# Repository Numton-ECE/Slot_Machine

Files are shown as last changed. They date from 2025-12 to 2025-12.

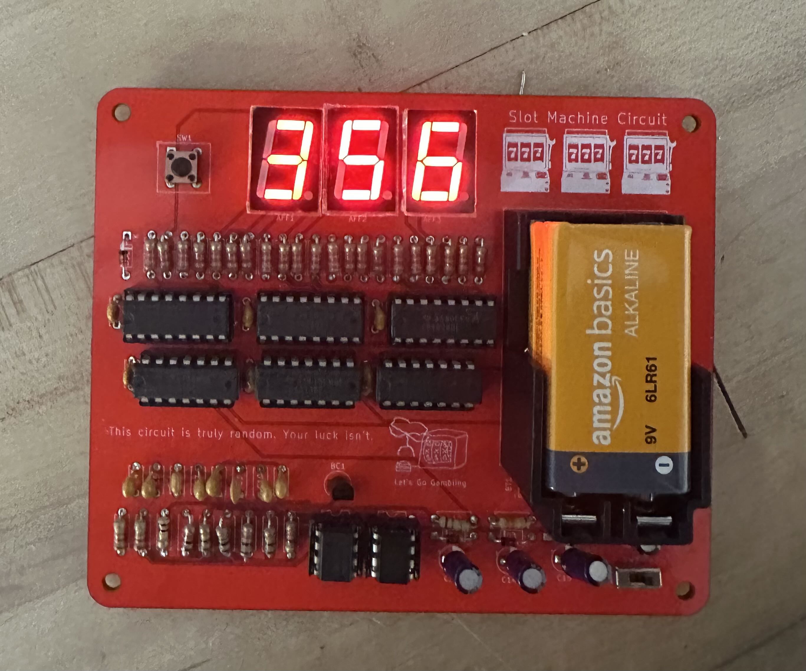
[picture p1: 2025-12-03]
media/Slot_Machine_Image.jpg

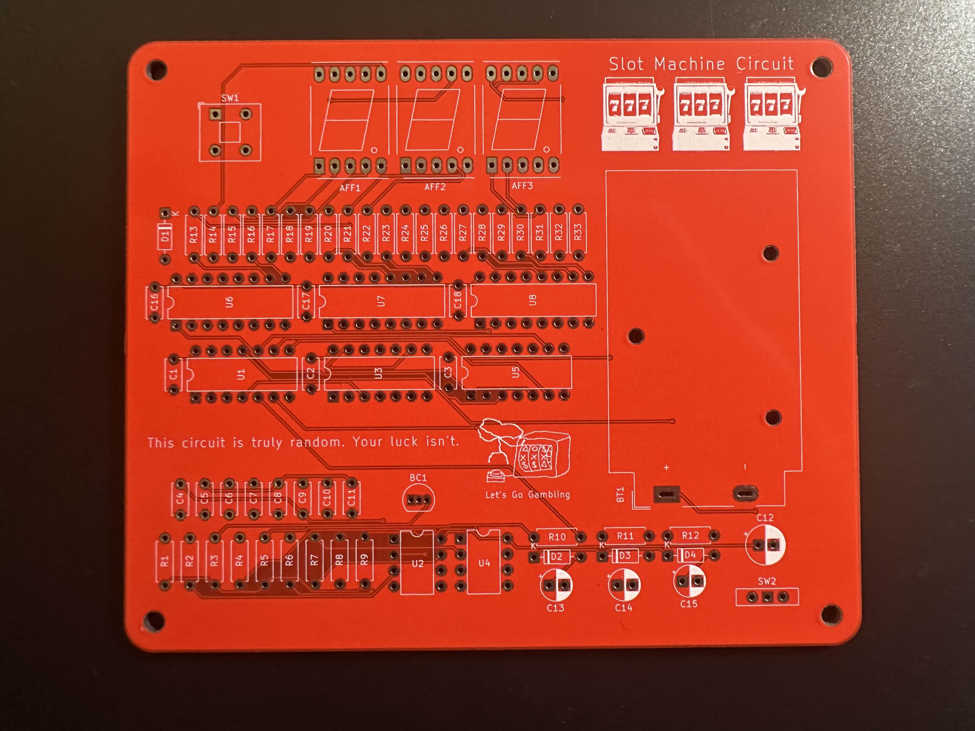
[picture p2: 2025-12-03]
media/Slot_Machine_Top_PCB.jpg

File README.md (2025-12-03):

Analog Slot Machine – 3-Digit Random Number Generator
=====================================================

This project is a fully discrete, CMOS-based 3-digit “slot machine” random number
generator designed in KiCad. A transistor noise source, analog amplification, and a
comparator generate a pseudo-random clock that drives three CD4026 decade counters and
7-segment LED displays. There is no microcontroller involved.

In normal use:
- A 2N3904 transistor is biased so it produces broadband electronic noise.
- An LM358 dual op-amp amplifies that noise and also creates a mid-supply reference (V_REF).
- An LM393 comparator compares the noisy signal to V_REF and outputs a pseudo-random
  digital clock (CLK).
- CD4013 flip-flops and a CD4081 AND gate handle the RUN state and decide when CLK is
  allowed through.
- Three CD4026 counters drive three 7-segment LED displays (e.g. 5161AS), forming a
  3-digit readout.
- When you hold the RUN pushbutton, the digits “spin”; when you release it, the
  current 3-digit number is frozen on the display.
- The whole circuit runs from a single 9 V battery (PP3).

Hardware Architecture
---------------------

1) Power and Decoupling
- Input is a 9 V battery, with VDD and GND as the main rails.
- Each IC has a 100 nF ceramic capacitor close to its power pins to keep the supply
  clean at high frequencies.
- Electrolytic capacitors on the 9 V rail provide bulk smoothing and help with
  startup and transients.
- This keeps both the analog and digital blocks stable and less sensitive to noise.

2) Noise and Clock Generation
- A 2N3904 NPN transistor is biased in a regime where it naturally produces broadband
  electronic noise. High-value resistors and a small capacitor shape this noise a bit.
- The LM358 op-amp does two jobs:
  - One channel generates V_REF, roughly at mid-supply.
  - The other channel amplifies and band-limits the noise so the comparator sees a
    clean, usable signal.
- The LM393 comparator compares the amplified noise to V_REF:
  - Whenever the noise crosses the reference, the comparator output toggles.
  - This produces a jittery, pseudo-random digital clock signal (CLK), which becomes
    the timing source for the counters.

3) Run / Sync Control and Clock Gating
- A CD4013 dual D-type flip-flop stores the RUN state and any related control bits.
- A dual-pole momentary RUN pushbutton, along with a few diodes and resistors,
  generates clean set/reset and edge-detect pulses so the flip-flop behaves nicely.
- A CD4081 quad 2-input AND gate combines:
  - The random clock (CLK),
  - The RUN state,
  - And any extra gating signals used per digit.
- When RUN is active, CLK passes through the AND gates and reaches the CD4026 counters.
- When RUN is inactive, the clock path is cut off and the counters simply hold their
  last values.
- An SPDT switch is available to select between different modes (for example,
  changing how reset or test behavior works), depending on how you choose to wire it.

4) Counters and Display
- Three CD4026 decade counters are used, one for each decimal digit:
  - Each counter receives a gated clock input from the CD4081, plus reset and control
    wiring for predictable startup.
  - CD4026 devices include built-in 7-segment decoding, so no extra decoder IC is needed.
- Three 7-segment LED displays (such as 5161AS) are driven directly from the CD4026
  outputs through current-limiting resistors (about 2.2 kΩ per segment).
- Together they form a simple 3-digit decimal display:
  - While you hold RUN, the digits advance quickly and look like spinning reels.
  - When you release RUN, the clock stops and the last 3-digit number stays on the
    display until the next run.

Usage
-----

- Open the KiCad project to inspect the schematic and PCB layout.
- If you want a physical board, generate Gerber and drill files from the KiCad PCB
  and send them to a PCB manufacturer.
- Assemble the board starting with resistors and capacitors, then sockets and
  connectors, and finally the ICs and displays.
- After soldering, check that the power rails are correct and there are no shorts
  between VDD and GND.
- Connect a 9 V battery.
- Press and hold the RUN button: the digits should spin rapidly.
- Release RUN: a random 3-digit number should remain displayed.

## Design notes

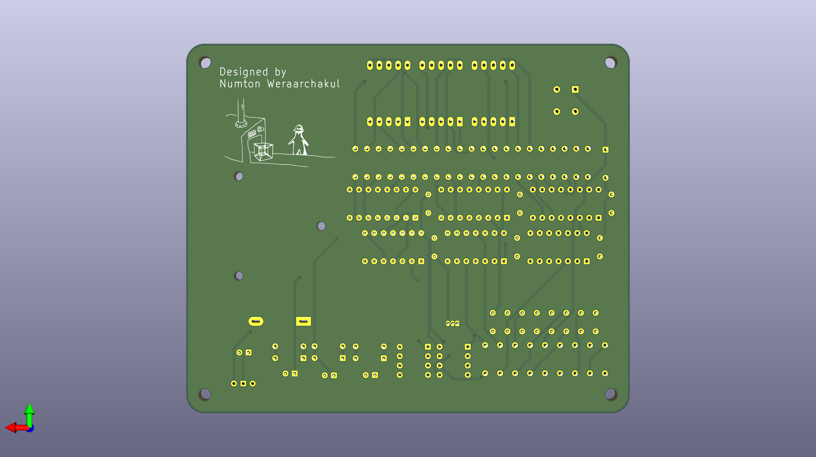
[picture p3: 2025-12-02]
media/Slot_Machine_Bottom.png

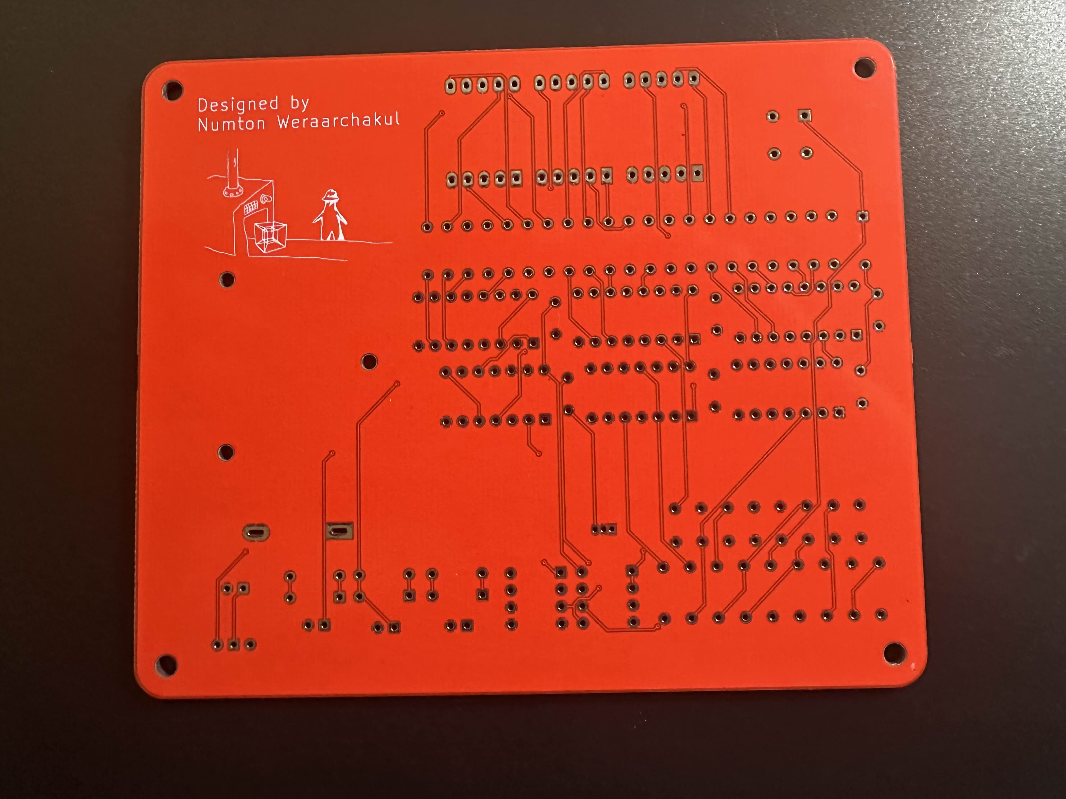
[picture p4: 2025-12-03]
media/Slot_Machine_Bottom_PCB.jpg

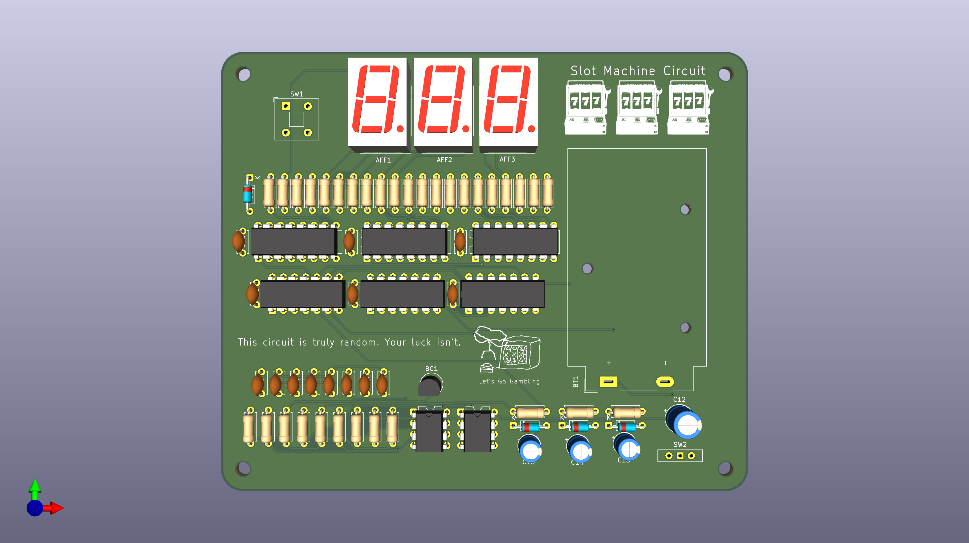
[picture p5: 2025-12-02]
media/Slot_Machine_Top.png

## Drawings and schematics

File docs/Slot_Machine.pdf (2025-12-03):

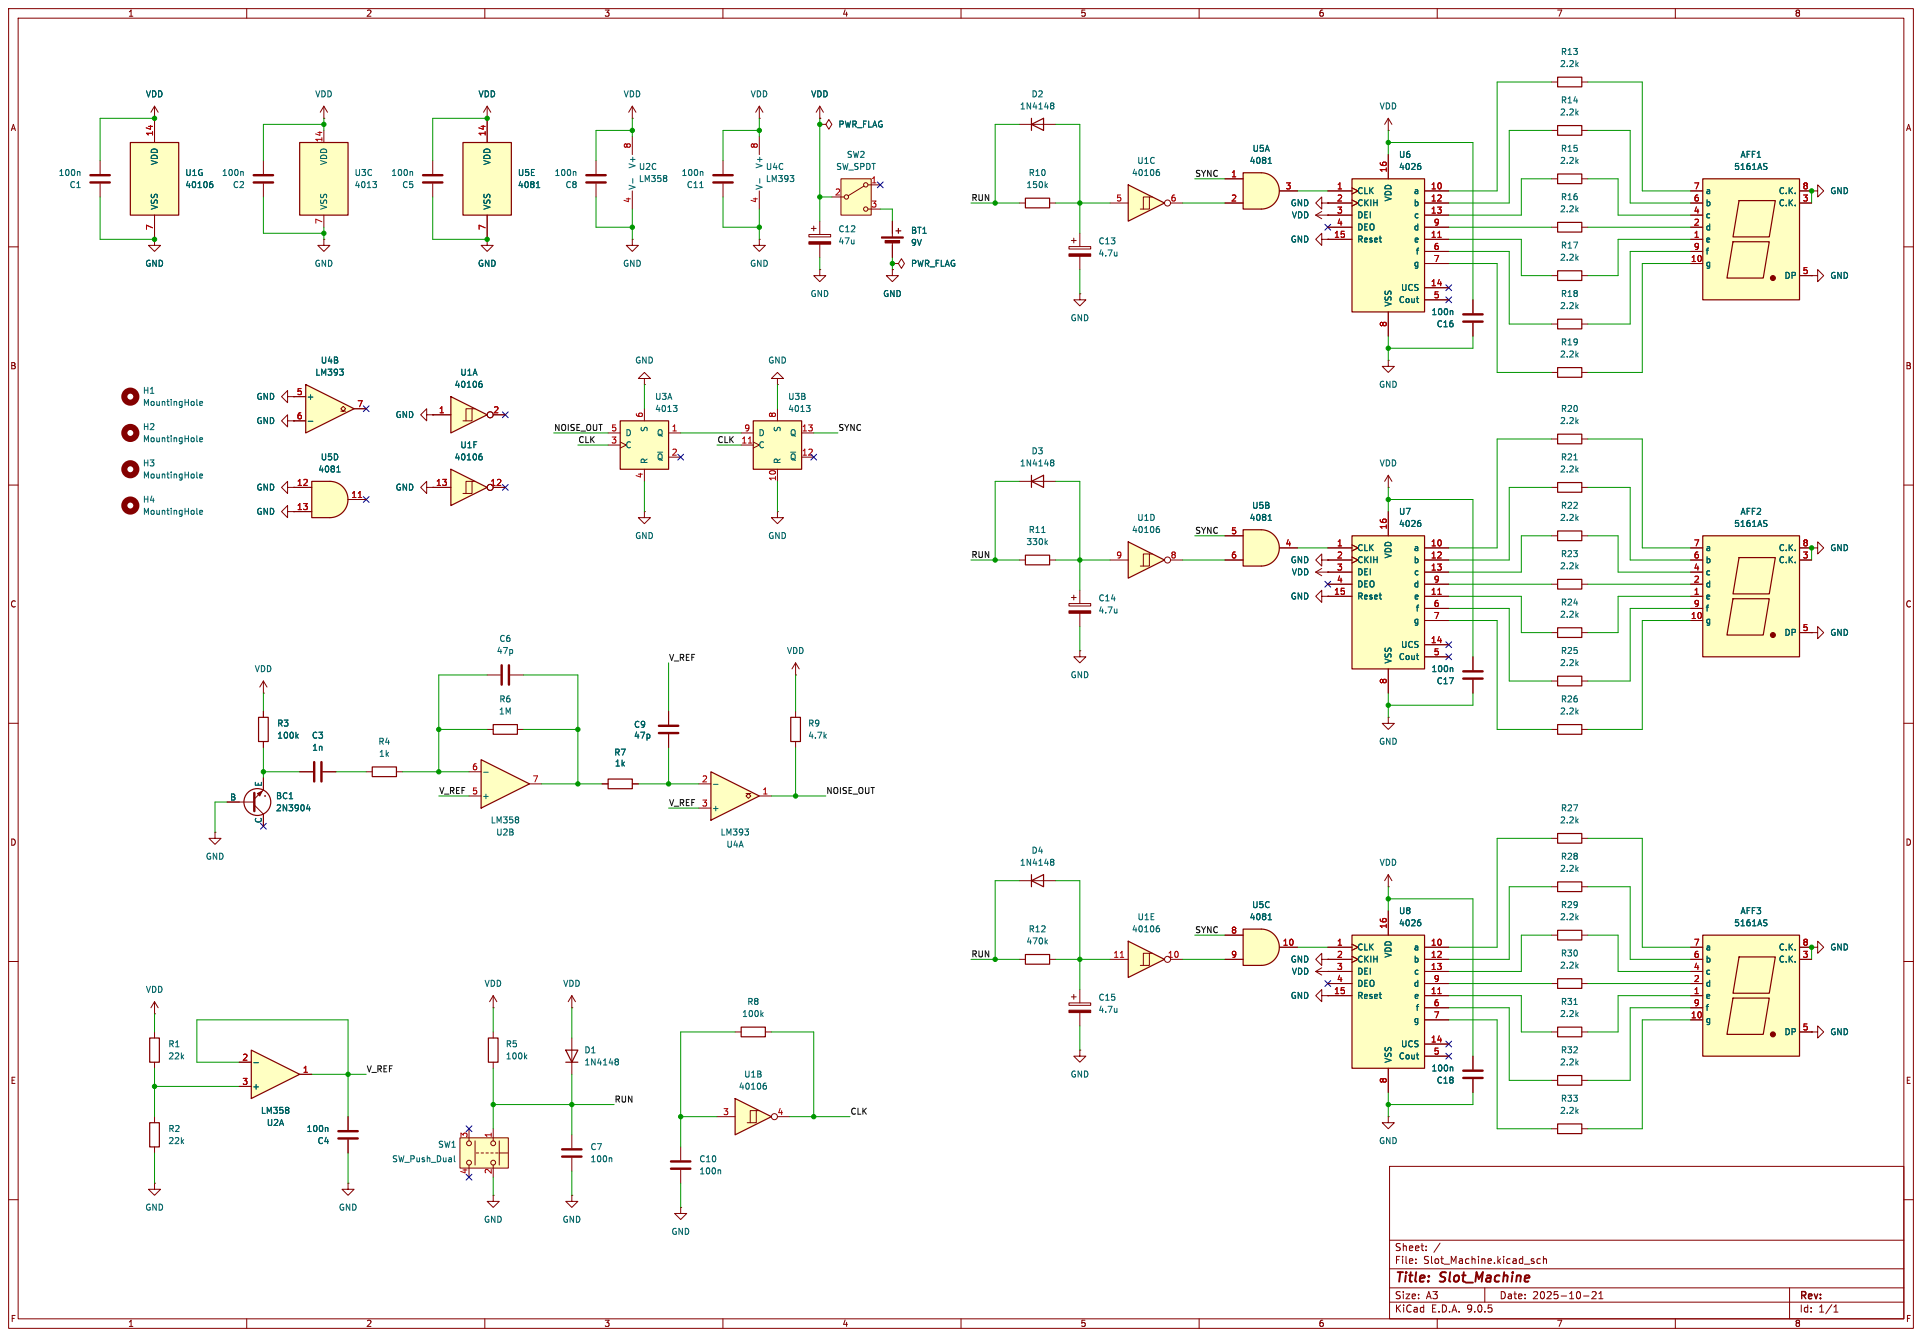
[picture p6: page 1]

40106 VDD 14 VSS 7 VDD
4081 VDD 14 VSS 7 GND GND

11 GND GND GND GND GND

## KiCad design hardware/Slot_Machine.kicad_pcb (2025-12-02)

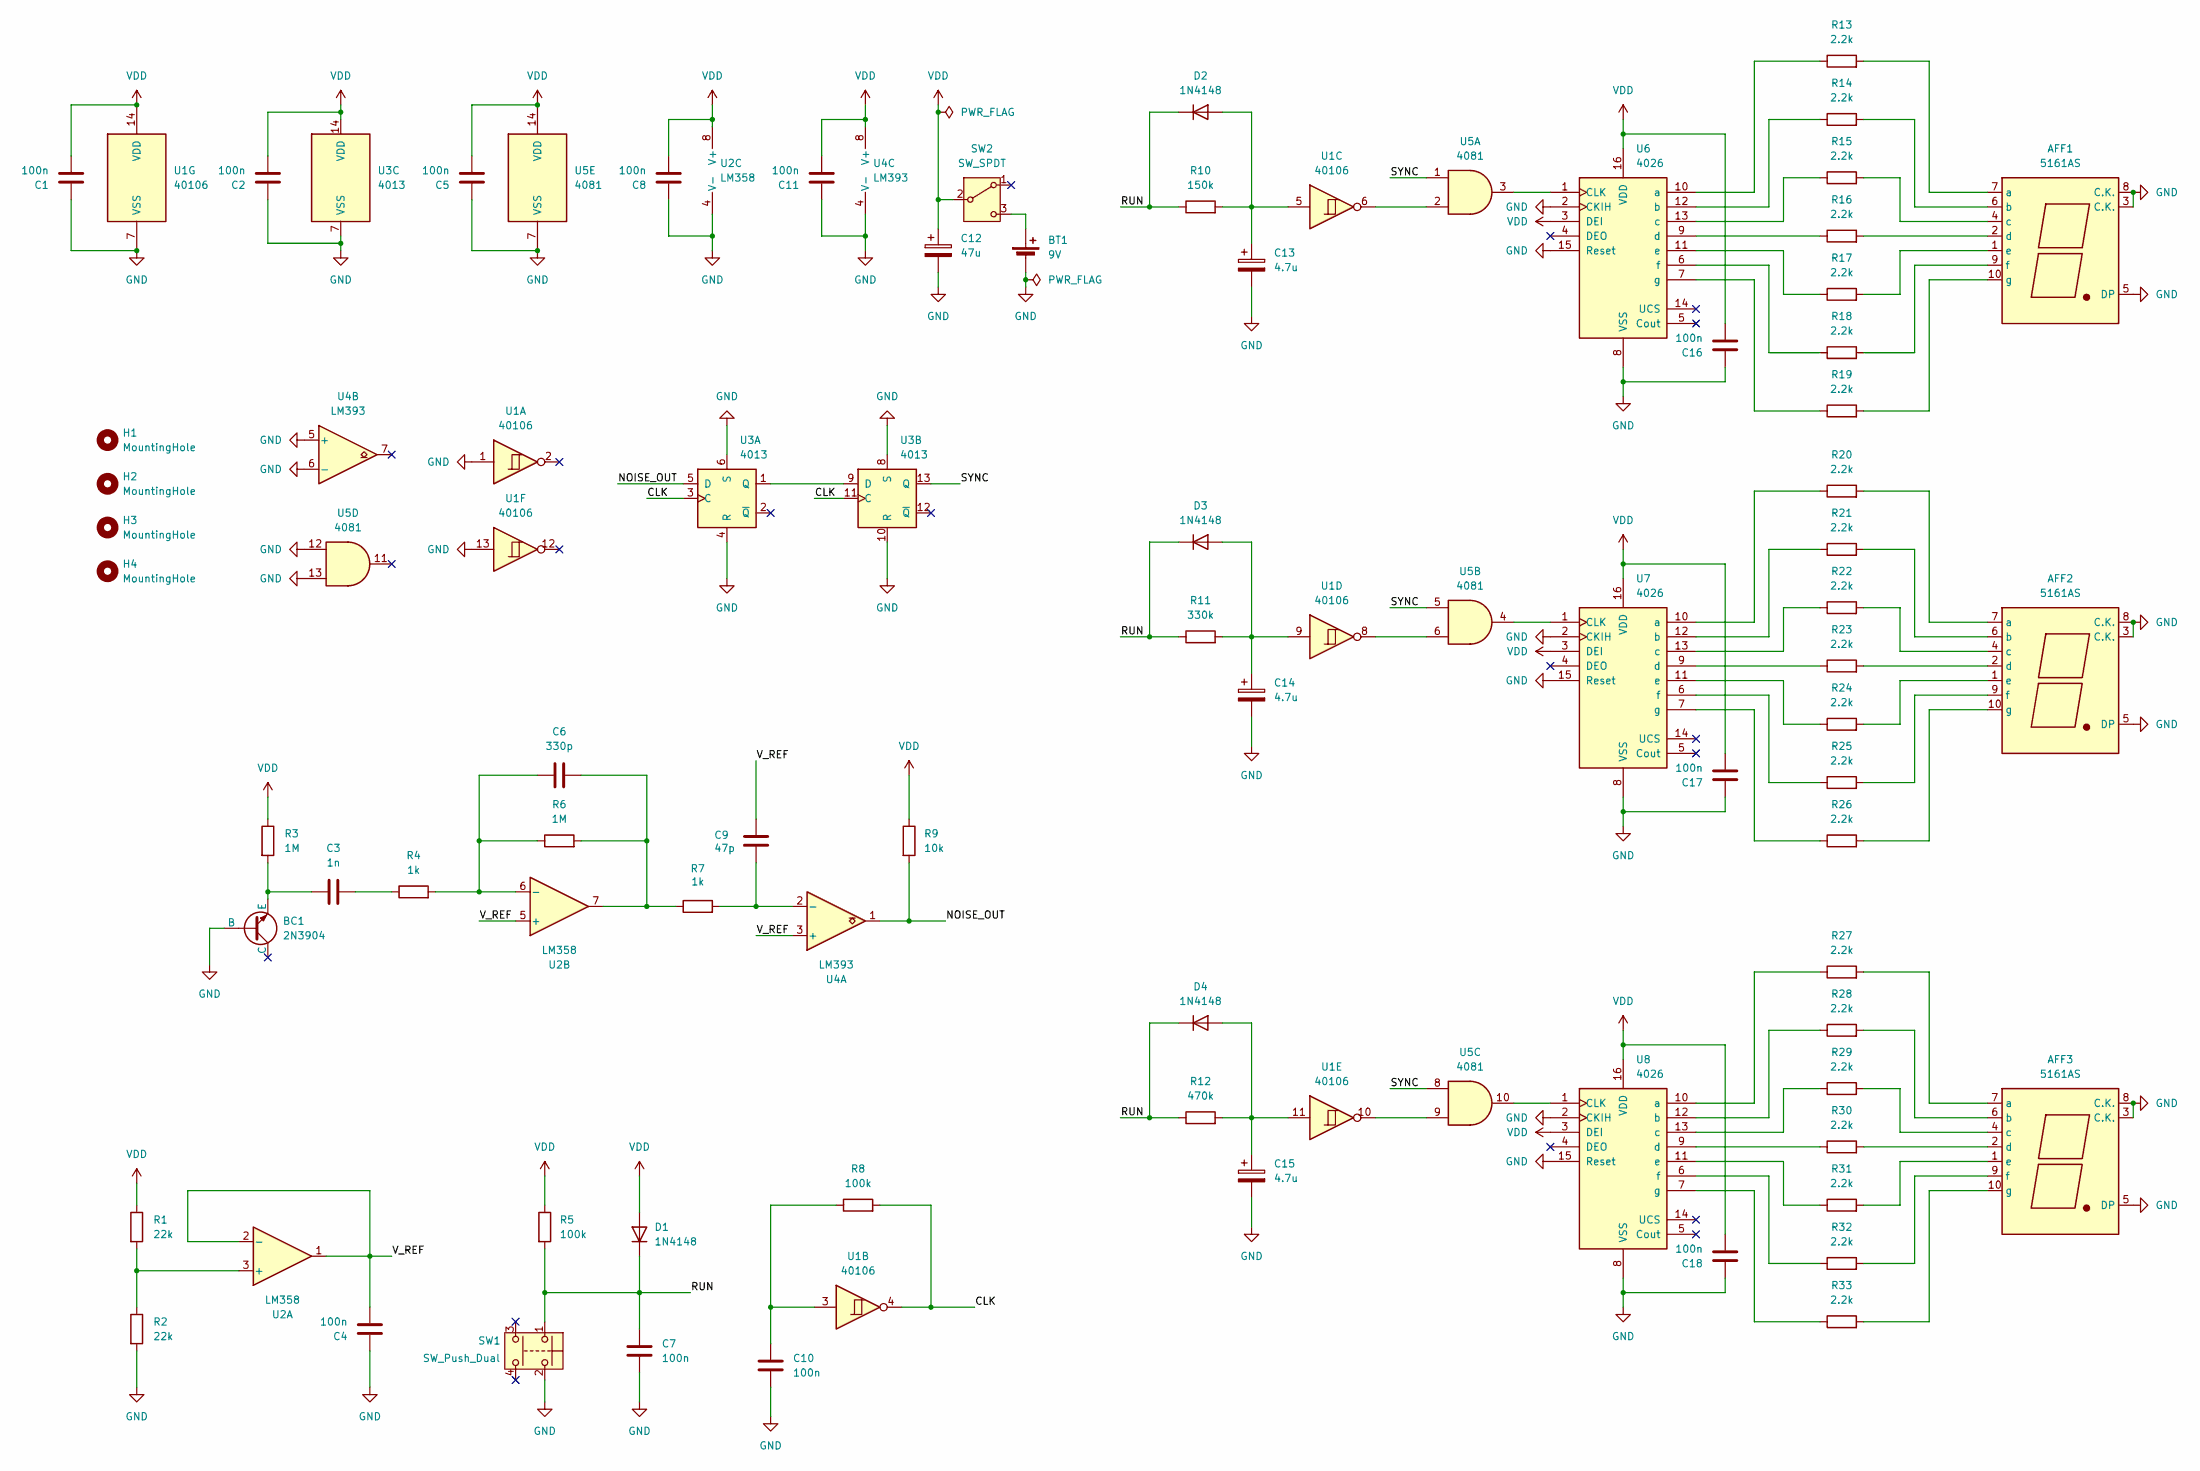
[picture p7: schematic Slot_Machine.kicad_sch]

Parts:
AFF1, AFF2, AFF3: 5161AS; 7SegmentLED_LTS6760_LTS6780
BC1: 2N3904; TO-92_Inline
BT1: 9V; BatteryHolder_MPD_BA9VPC_1xPP3
C1, C2, C4, C5, C7, C8, C10, C11, C16, C17, C18: 100n; C_Disc_D5.0mm_W2.5mm_P5.00mm
C3: 1n; C_Disc_D5.0mm_W2.5mm_P5.00mm
C6: 330p; C_Disc_D5.0mm_W2.5mm_P5.00mm
C9: 47p; C_Disc_D5.0mm_W2.5mm_P5.00mm
C12: 47u; CP_Radial_D6.3mm_P2.50mm
C13, C14, C15: 4.7u; CP_Radial_D5.0mm_P2.50mm
D1, D2, D3, D4: 1N4148; D_DO-35_SOD27_P7.62mm_Horizontal
H1, H2, H3, H4: MountingHole; MountingHole_3.2mm_M3
R1, R2: 22k; R_Axial_DIN0207_L6.3mm_D2.5mm_P7.62mm_Horizontal
R3, R6: 1M; R_Axial_DIN0207_L6.3mm_D2.5mm_P7.62mm_Horizontal
R4, R7: 1k; R_Axial_DIN0207_L6.3mm_D2.5mm_P7.62mm_Horizontal
R5, R8: 100k; R_Axial_DIN0207_L6.3mm_D2.5mm_P7.62mm_Horizontal
R9: 10k; R_Axial_DIN0207_L6.3mm_D2.5mm_P7.62mm_Horizontal
R10: 150k; R_Axial_DIN0207_L6.3mm_D2.5mm_P7.62mm_Horizontal
R11: 330k; R_Axial_DIN0207_L6.3mm_D2.5mm_P7.62mm_Horizontal
R12: 470k; R_Axial_DIN0207_L6.3mm_D2.5mm_P7.62mm_Horizontal
R13, R14, R15, R16, R17, R18, R19, R20, R21, R22, R23, R24, R25, R26, R27, R28, R29, R30, R31, R32, R33: 2.2k; R_Axial_DIN0207_L6.3mm_D2.5mm_P7.62mm_Horizontal
SW1: SW_Push_Dual; SW_Push_2P1T_Toggle_CK_PVA1xxH4xxxxxxV2
SW2: SW_SPDT; SW_Slide-03_Wuerth-WS-SLTV_10x2.5x6.4_P2.54mm_Custom
U1: 40106; DIP-14_W7.62mm
U2: LM358; DIP-8_W7.62mm
U3: 4013; DIP-14_W7.62mm
U4: LM393; DIP-8_W7.62mm
U5: 4081; DIP-14_W7.62mm
U6, U7, U8: 4026; DIP-16_W7.62mm

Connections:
/CLK: R8.2, U1.4, U3.3 (C), U3.11 (C)
/NOISE_OUT: R9.2, U3.5 (D), U4.1
/RUN: C7.1, D1.1 (K), D2.1 (K), D3.1 (K), D4.1 (K), R5.2, R10.1, R11.1, R12.1, SW1.1
/SYNC: U3.13 (Q), U5.1, U5.5, U5.8
/V_REF: C4.2, C9.1, U2.1, U2.2 (-), U2.5 (+), U4.3 (+)
GND: AFF1.3 (C.K.), AFF1.5 (DP), AFF1.8 (C.K.), AFF2.3 (C.K.), AFF2.5 (DP), AFF2.8 (C.K.), AFF3.3 (C.K.), AFF3.5 (DP), AFF3.8 (C.K.), BC1.2 (B), BT1.2 (-), C1.1, C2.1, C4.1, C5.1, C7.2, C8.1, C10.2, C11.1, C12.2, C13.2, C14.2, C15.2, C16.1, C17.1, C18.1, R2.2, SW1.2, U1.1, U1.7 (VSS), U1.13, U2.4 (V-), U3.4 (R), U3.6 (S), U3.7 (VSS), U3.8 (S), U3.10 (R), U4.4 (V-), U4.5 (+), U4.6 (-), U5.7 (VSS), U5.12, U5.13, U6.2 (CKIH), U6.8 (VSS), U6.15 (Reset), U7.2 (CKIH), U7.8 (VSS), U7.15 (Reset), U8.2 (CKIH), U8.8 (VSS), U8.15 (Reset)
unnamed: AFF1.7 (a), R13.2
unnamed: AFF1.6 (b), R14.2
unnamed: AFF1.4 (c), R15.2
unnamed: AFF1.2 (d), R16.2
unnamed: AFF1.1 (e), R17.2
unnamed: AFF1.9 (f), R18.2
unnamed: AFF1.10 (g), R19.2
unnamed: AFF2.7 (a), R20.2
unnamed: AFF2.6 (b), R21.2
unnamed: AFF2.4 (c), R22.2
unnamed: AFF2.2 (d), R23.2
unnamed: AFF2.1 (e), R24.2
unnamed: AFF2.9 (f), R25.2
unnamed: AFF2.10 (g), R26.2
unnamed: AFF3.7 (a), R27.2
unnamed: AFF3.6 (b), R28.2
unnamed: AFF3.4 (c), R29.2
unnamed: AFF3.2 (d), R30.2
unnamed: AFF3.1 (e), R31.2
unnamed: AFF3.9 (f), R32.2
unnamed: AFF3.10 (g), R33.2
unnamed: BC1.3 (E), C3.1, R3.2
unnamed: BT1.1 (+), SW2.3 (C)
unnamed: C3.2, R4.1
unnamed: C6.2, R6.2, R7.1, U2.7
unnamed: C10.1, R8.1, U1.3
unnamed: C13.1, D2.2 (A), R10.2, U1.5
unnamed: C14.1, D3.2 (A), R11.2, U1.9
unnamed: C15.1, D4.2 (A), R12.2, U1.11
unnamed: U1.6, U5.2
unnamed: U1.8, U5.6
unnamed: U1.10, U5.9
unnamed: R1.2, R2.1, U2.3 (+)
unnamed: C6.1, R4.2, R6.1, U2.6 (-)
unnamed: U3.1 (Q), U3.9 (D)
unnamed: C9.2, R7.2, U4.2 (-)
unnamed: U5.3, U6.1 (CLK)
unnamed: R13.1, U6.10 (a)
unnamed: R14.1, U6.12 (b)
unnamed: R15.1, U6.13 (c)
unnamed: R16.1, U6.9 (d)
unnamed: R17.1, U6.11 (e)
unnamed: R18.1, U6.6 (f)
unnamed: R19.1, U6.7 (g)
unnamed: U5.4, U7.1 (CLK)
unnamed: R20.1, U7.10 (a)
unnamed: R21.1, U7.12 (b)
unnamed: R22.1, U7.13 (c)
unnamed: R23.1, U7.9 (d)
unnamed: R24.1, U7.11 (e)
unnamed: R25.1, U7.6 (f)
unnamed: R26.1, U7.7 (g)
unnamed: U5.10, U8.1 (CLK)
unnamed: R27.1, U8.10 (a)
unnamed: R28.1, U8.12 (b)
unnamed: R29.1, U8.13 (c)
unnamed: R30.1, U8.9 (d)
unnamed: R31.1, U8.11 (e)
unnamed: R32.1, U8.6 (f)
unnamed: R33.1, U8.7 (g)
VDD: C1.2, C2.2, C5.2, C8.2, C11.2, C12.1, C16.2, C17.2, C18.2, D1.2 (A), R1.1, R3.1, R5.1, R9.1, SW2.2 (B), U1.14 (VDD), U2.8 (V+), U3.14 (VDD), U4.8 (V+), U5.14 (VDD), U6.3 (DEI), U6.16 (VDD), U7.3 (DEI), U7.16 (VDD), U8.3 (DEI), U8.16 (VDD)

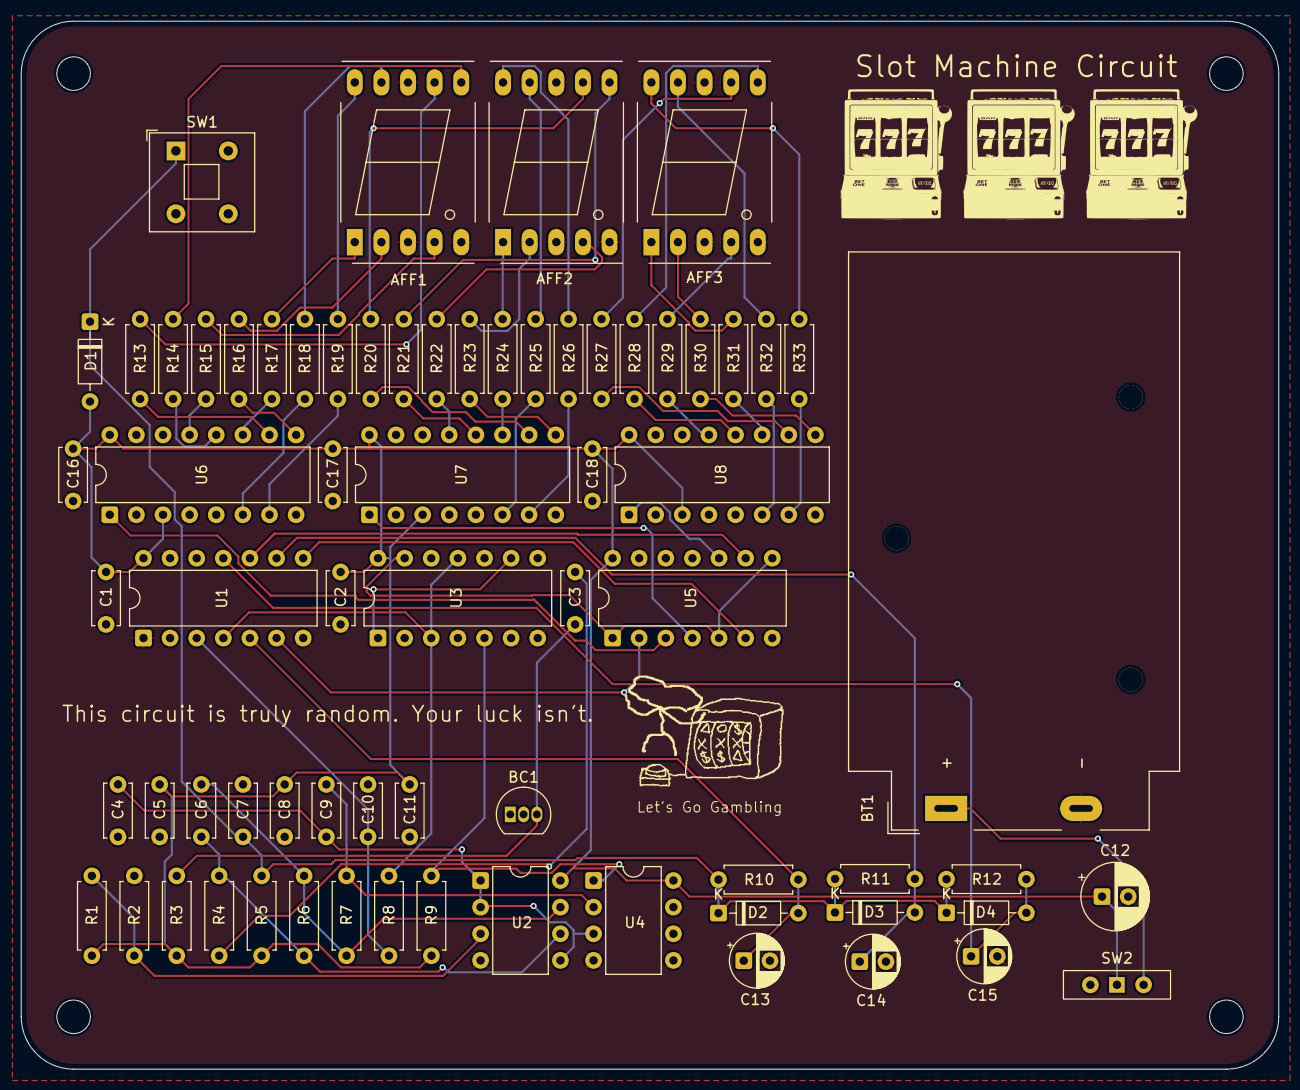
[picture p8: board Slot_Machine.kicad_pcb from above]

Board: 2 copper layers, 120.0 x 100.0 mm, 79 parts (1 on the bottom side), 67 nets.

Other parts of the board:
G1, G2, G3, G4, G5: LOGO
